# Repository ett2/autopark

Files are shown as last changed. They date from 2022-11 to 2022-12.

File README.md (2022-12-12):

# AutoPark
Repo for the embedded portion of AutoPark senior design project

Includes: 
- Lots of testing modules as keepsakes
- Fob
- Sensors
- State Driver
- Screen testing

Part of this project was developed for a course called ENGI 301. All relevant files to that class are in the ENGI 301 folder.
For further information about that portion of the project, go to:
https://www.hackster.io/eunice-tan/remote-controlled-lighting-system-b601c9

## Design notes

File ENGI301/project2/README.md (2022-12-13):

# ENGI 301 Project 2 Documentation

I developed a PCB design for the fob portion of the AutoPark project, which is designed to be a first-iteration test of the components in a PCB.
This was also designed as a part of the ENGI 301 Project 2.

Included in this directory:
- Schematic file
- Board file
- Parts library
- Bill of Materials
- Gerber files
- Pictures of the PCB design

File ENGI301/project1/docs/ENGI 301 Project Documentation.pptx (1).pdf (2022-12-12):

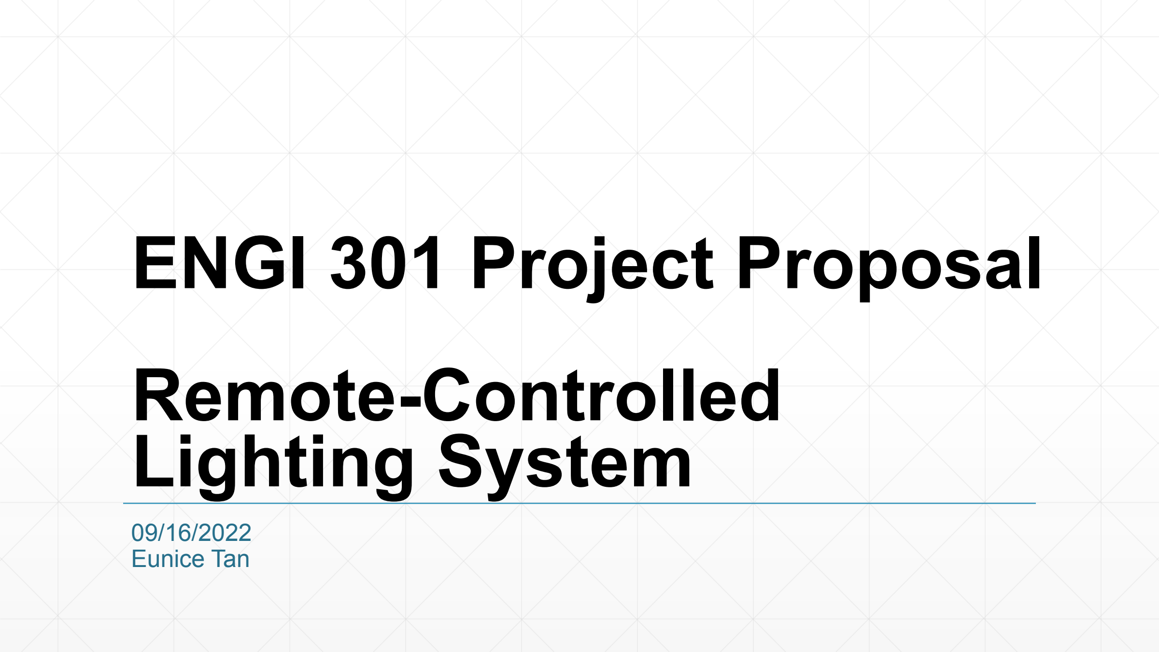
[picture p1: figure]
ENGI 301 Project Proposal; Remote-Controlled Lighting System; 09/16/2022 Eunice Tan

# Background Information

- Senior Design Project: to design a self-parking vehicle
- Need a way to communicate between the user and the golf cart used in the project
- Idea: a fob that communicates with the central processing unit of the motor control to determine state control for the vehicle
- MVP:
- Must communicate states between Arduino and BeagleBone Black with RF
- Must show state on LCD screen
- Ultrasonic sensor induces emergency stop state
- Four modes: Curbside Parking, Normal Parking, Idle, and Emergency Stop

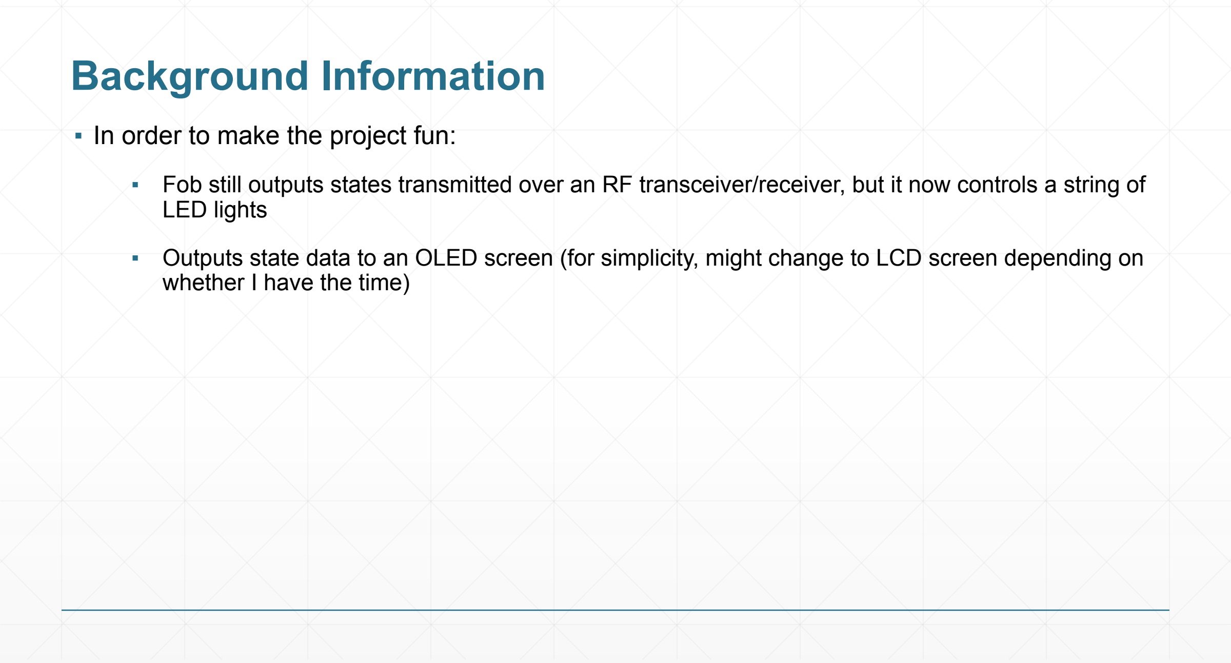
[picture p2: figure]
Background Information; ▪ In order to make the project fun:; LED lights; whether I have the time)

- Fob still outputs states transmitted over an RF transceiver/receiver, but it now controls a string of
- Outputs state data to an OLED screen (for simplicity, might change to LCD screen depending on

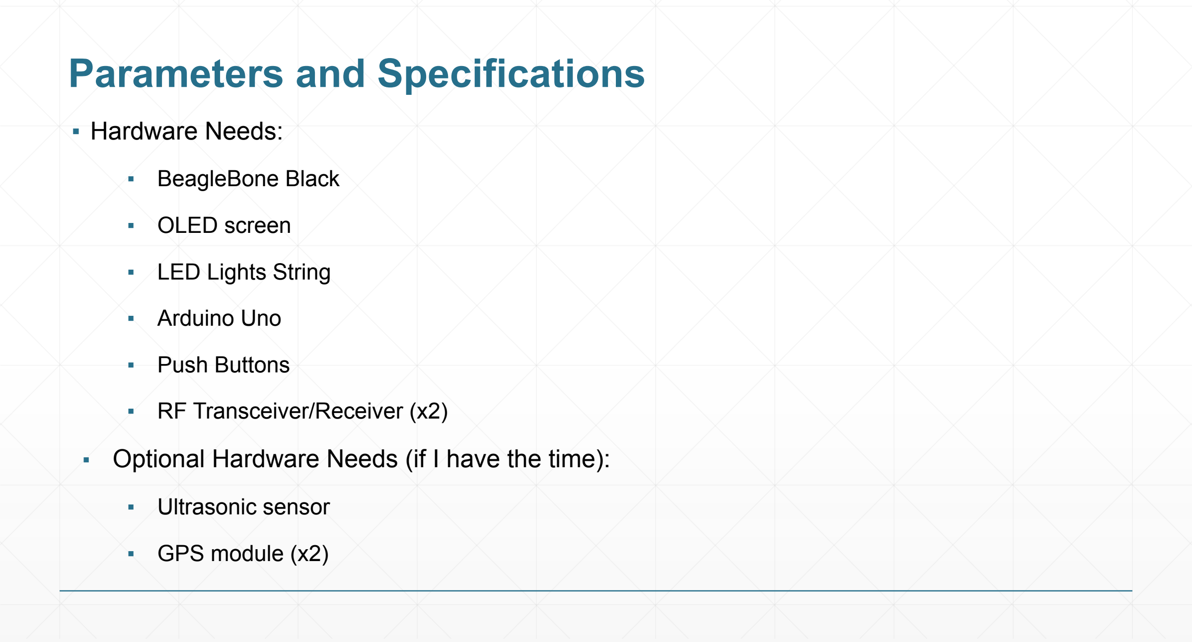
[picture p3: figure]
Parameters and Specifications; ▪ Hardware Needs:; ▪ BeagleBone Black; ▪ OLED screen; ▪ LED Lights String; ▪ Arduino Uno; ▪ Push Buttons; ▪ RF Transceiver/Receiver (x2); ▪ Ultrasonic sensor; ▪ GPS module (x2)

- Optional Hardware Needs (if I have the time):

# Parameters and Specifications

- Software Needs:
- BeagleBone Black displays state and controls the LEDs
- OLED screen displays current state
- LEDs light up differently depending on the current state
- Arduino Uno decides state transitions and communicates them to the BeagleBone
- Push buttons decide state transitions
- RF Transceiver/Receiver communicates between BeagleBone and Arduino
- Optional Software Needs:
- Ultrasonic sensor contributes to state change; BeagleBone then decides final states
- GPS modules send location information between Arduino and BeagleBone

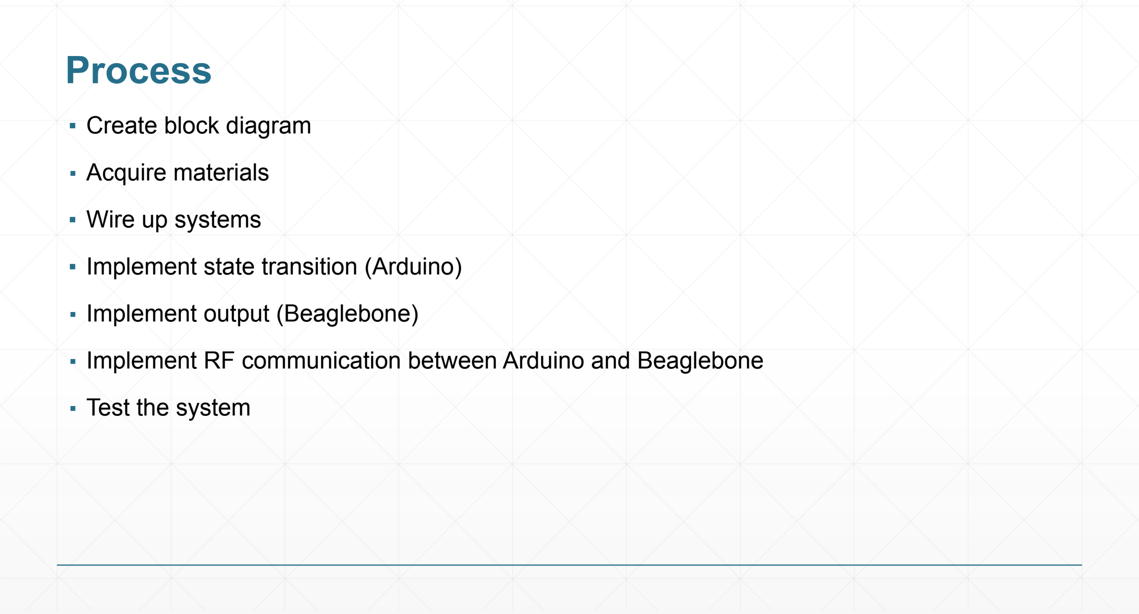
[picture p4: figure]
Process; ▪ Create block diagram; ▪ Acquire materials; ▪ Wire up systems; ▪ Implement state transition (Arduino); ▪ Implement output (Beaglebone); ▪ Test the system

- Implement RF communication between Arduino and Beaglebone

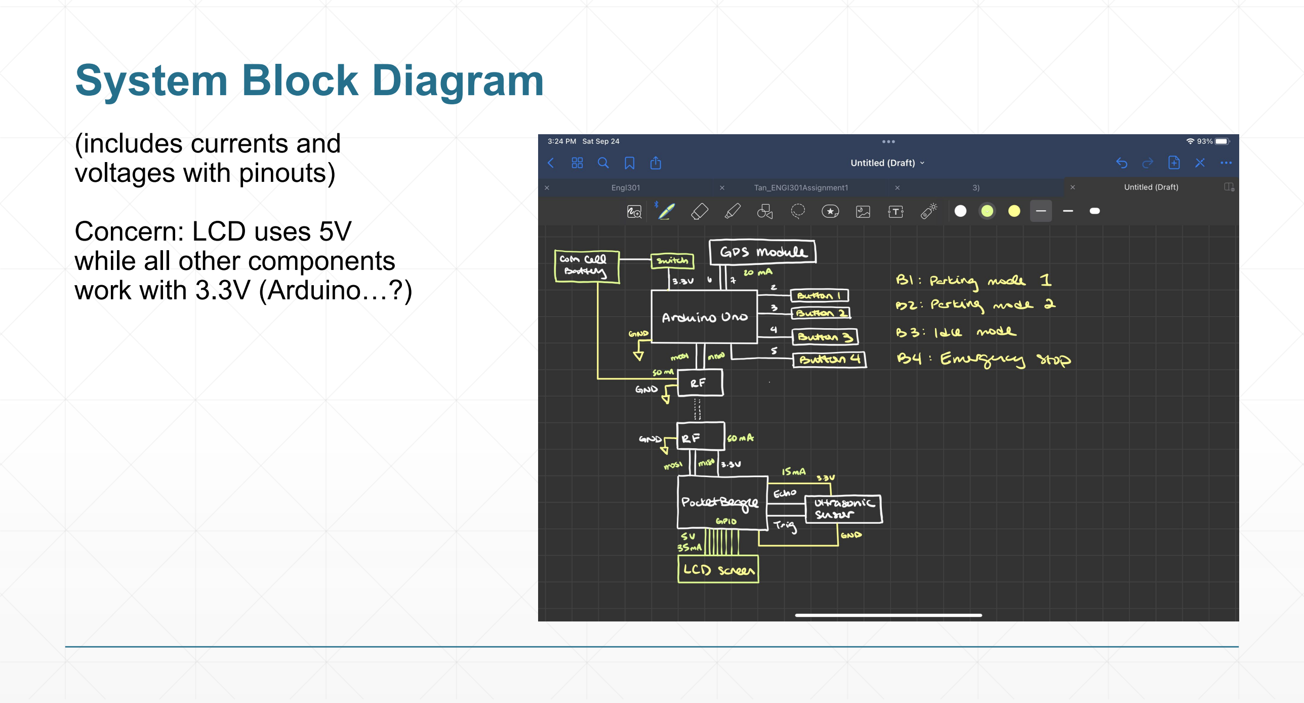
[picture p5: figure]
System Block Diagram; (includes currents and voltages with pinouts); Concern: LCD uses 5V while all other components work with 3.3V (Arduino…?)

# Components

Component | Link to Component
BeagleBone Black | N/A
Arduino Uno | https://www.amazon.com/Arduino-A000066-ARDUINO-UNO-R3/dp/B008GRTS V6
RF Module (x2) | https://www.adafruit.com/product/3071
GPS Module (x1) | https://www.adafruit.com/product/746
OLED Screen | https://www.adafruit.com/product/2719
Ultrasonic Sensor | https://www.adafruit.com/product/3942
LED Lights String | https://www.adafruit.com/product/1138?length=1
Push Buttons | N/A
Colored LEDs | N/A

Need all components to be purchased by instructor listed; additional components may be purchased by student

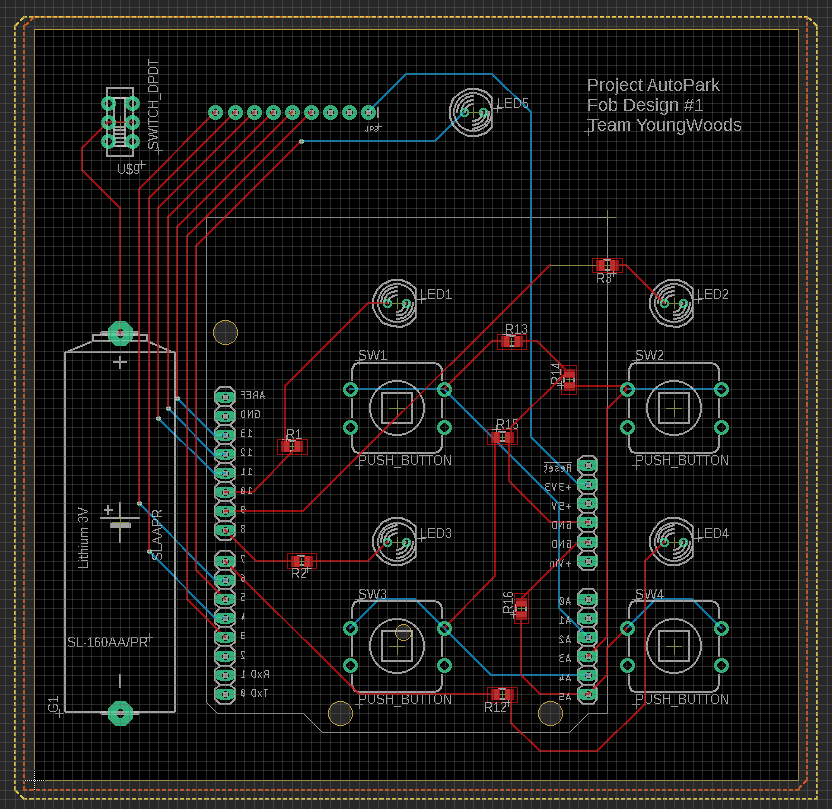
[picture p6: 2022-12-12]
ENGI301/project2/docs/fob_brd.png

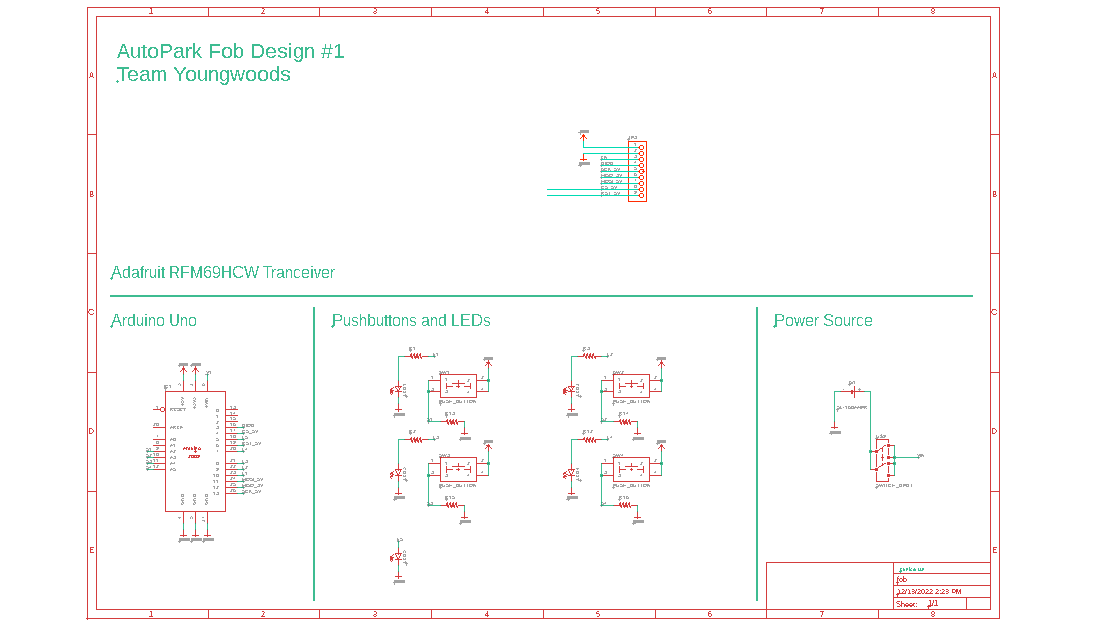
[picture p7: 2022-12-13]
ENGI301/project2/docs/fob_sch.png

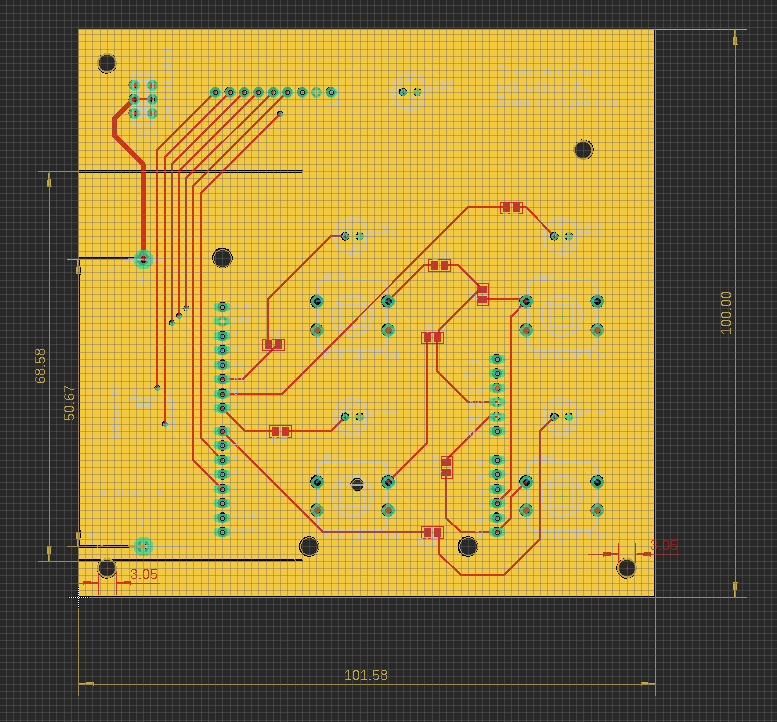
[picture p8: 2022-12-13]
ENGI301/project2/docs/fob_brd_final.png

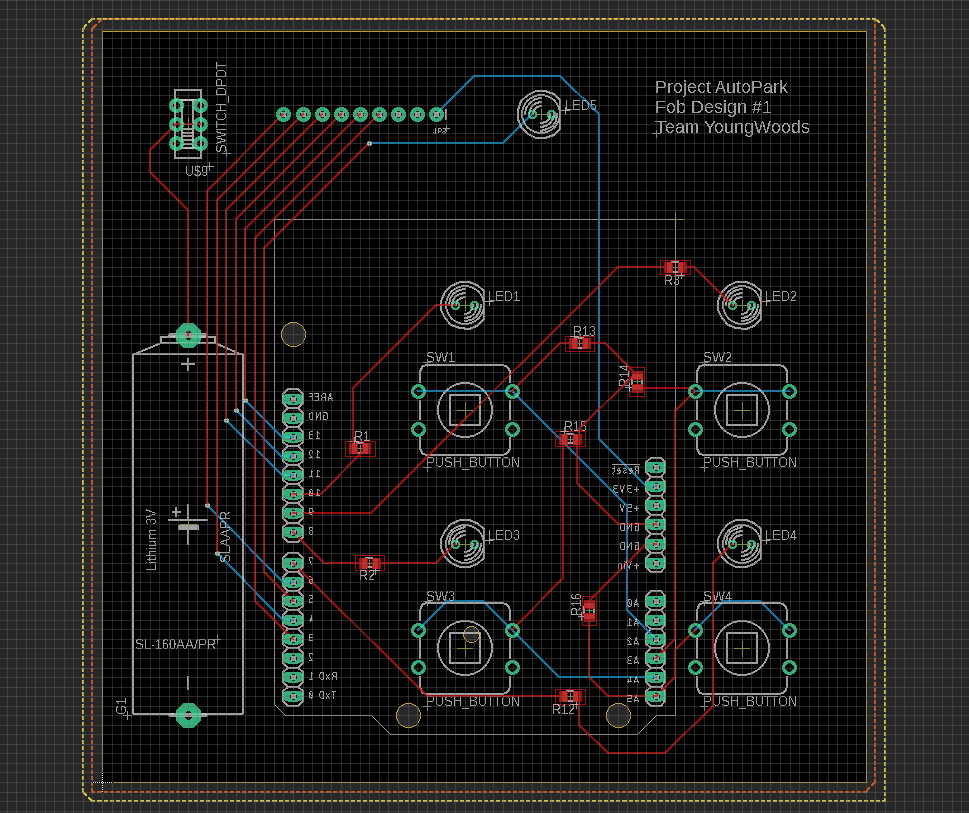
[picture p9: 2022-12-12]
ENGI301/project2/docs/fob_brd3.png

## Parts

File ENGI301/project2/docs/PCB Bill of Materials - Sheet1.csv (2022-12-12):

Part Name | Designator | Manufacturer/MPN | Quanitity | Description
Arduino Uno | Arduino 2009 | Arduino | 1 | Microcontroller board
6-pin Switch | SWITCH_DPDT | Various manufacturers | 1 | Found in FEP: no need to order
5mm LED | LED1, LED2, LED3, LED4, LED5 | Various manufacturers | 5 | Found in OEDK and FEP: no need to order
RFM69HCW Radio Module | JP3 | Adafruit | 1 | Radio transceiver/receiver module
Tactile Push Buttons | SW1, SW2, SW3, SW4 | Various manufacturers | 4 | Found in OEDK: no need to order
100-ohm resistor | R1, R2, R3, R12, R13, R14, R15, R16 | Various manufacturers | 8 | Found in FEP: no need to order
Through-hole power source connector | G1 | N/A | 1 | Can connect to various power sources depending on need

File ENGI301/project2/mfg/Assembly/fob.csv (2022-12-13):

Qty | Value | Device | Package | Parts | Description | POPULARITY
1 |  | ARDUINO2009_10 | ARDUINO2009 | IC1 | The Arduino Duemilanove (2009") is a microcontroller board based on the ATmega168 or ATmega328."
1 |  | HEADER-1X970MIL | 1X09_ROUND_70 | JP3 | PIN HEADER
5 |  | LED5MM | LED5MM | LED1, LED2, LED3, LED4, LED5 | LED | 93
8 |  | R_R0805 | R0805 | R1, R2, R3, R12, R13, R14, R15, R16 | RESISTOR, American symbol
4 | PUSH_BUTTON | PUSH_BUTTON | BUTTON_12.5MM | SW1, SW2, SW3, SW4
1 | SL-160AA/PR | SL-160AA/PR | SL-160AA/PR | G1 | LI BATTERY Sonnenschein | 1
1 | SWITCH_DPDT | SWITCH_DPDT | JS_DPDT_TH | U$9

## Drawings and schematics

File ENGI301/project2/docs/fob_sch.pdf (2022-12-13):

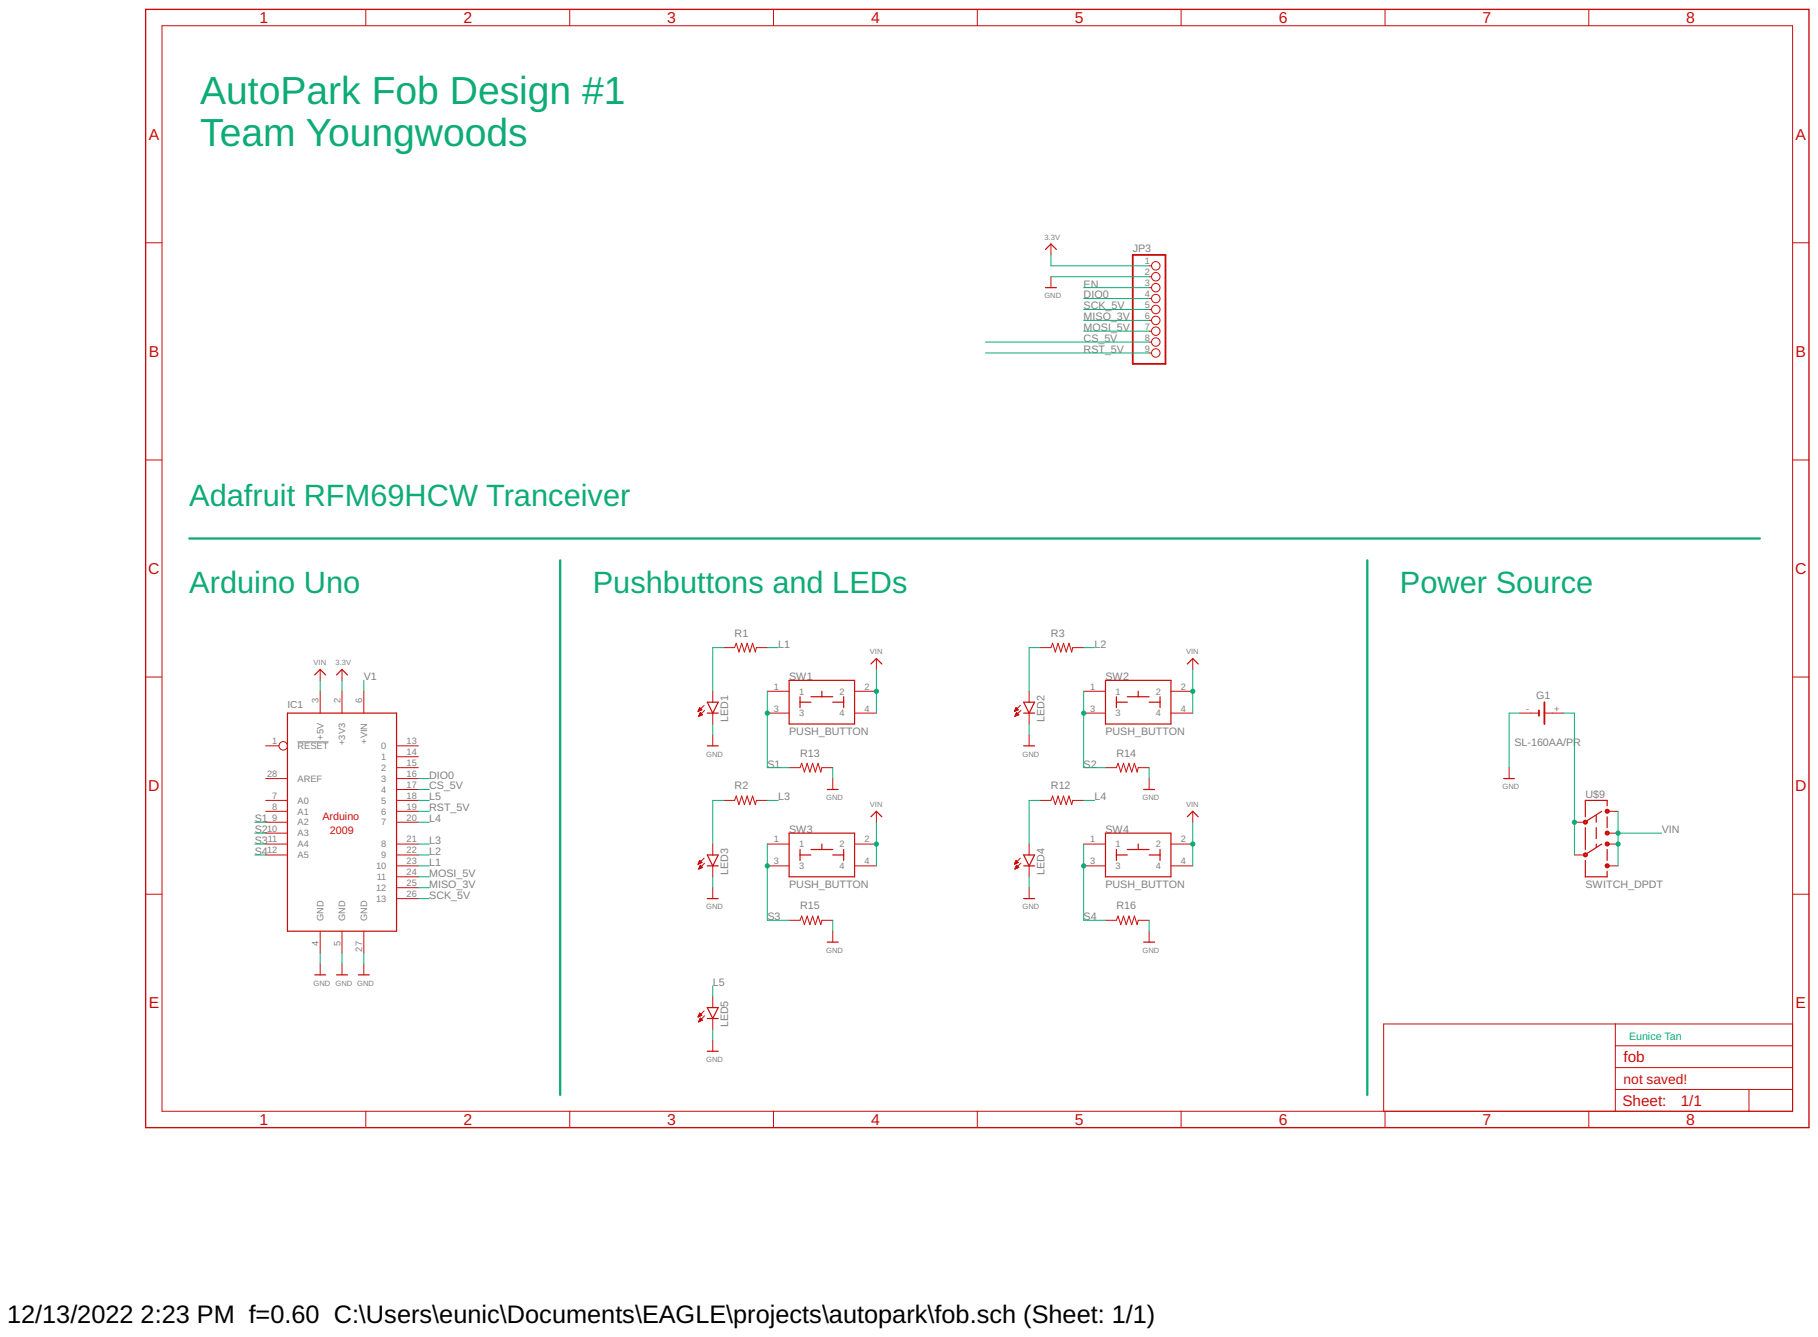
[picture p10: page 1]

12/13/2022 2:23 PM f=0.60 C:\Users\eunic\Documents\EAGLE\projects\autopark\fob.sch (Sheet: 1/1)

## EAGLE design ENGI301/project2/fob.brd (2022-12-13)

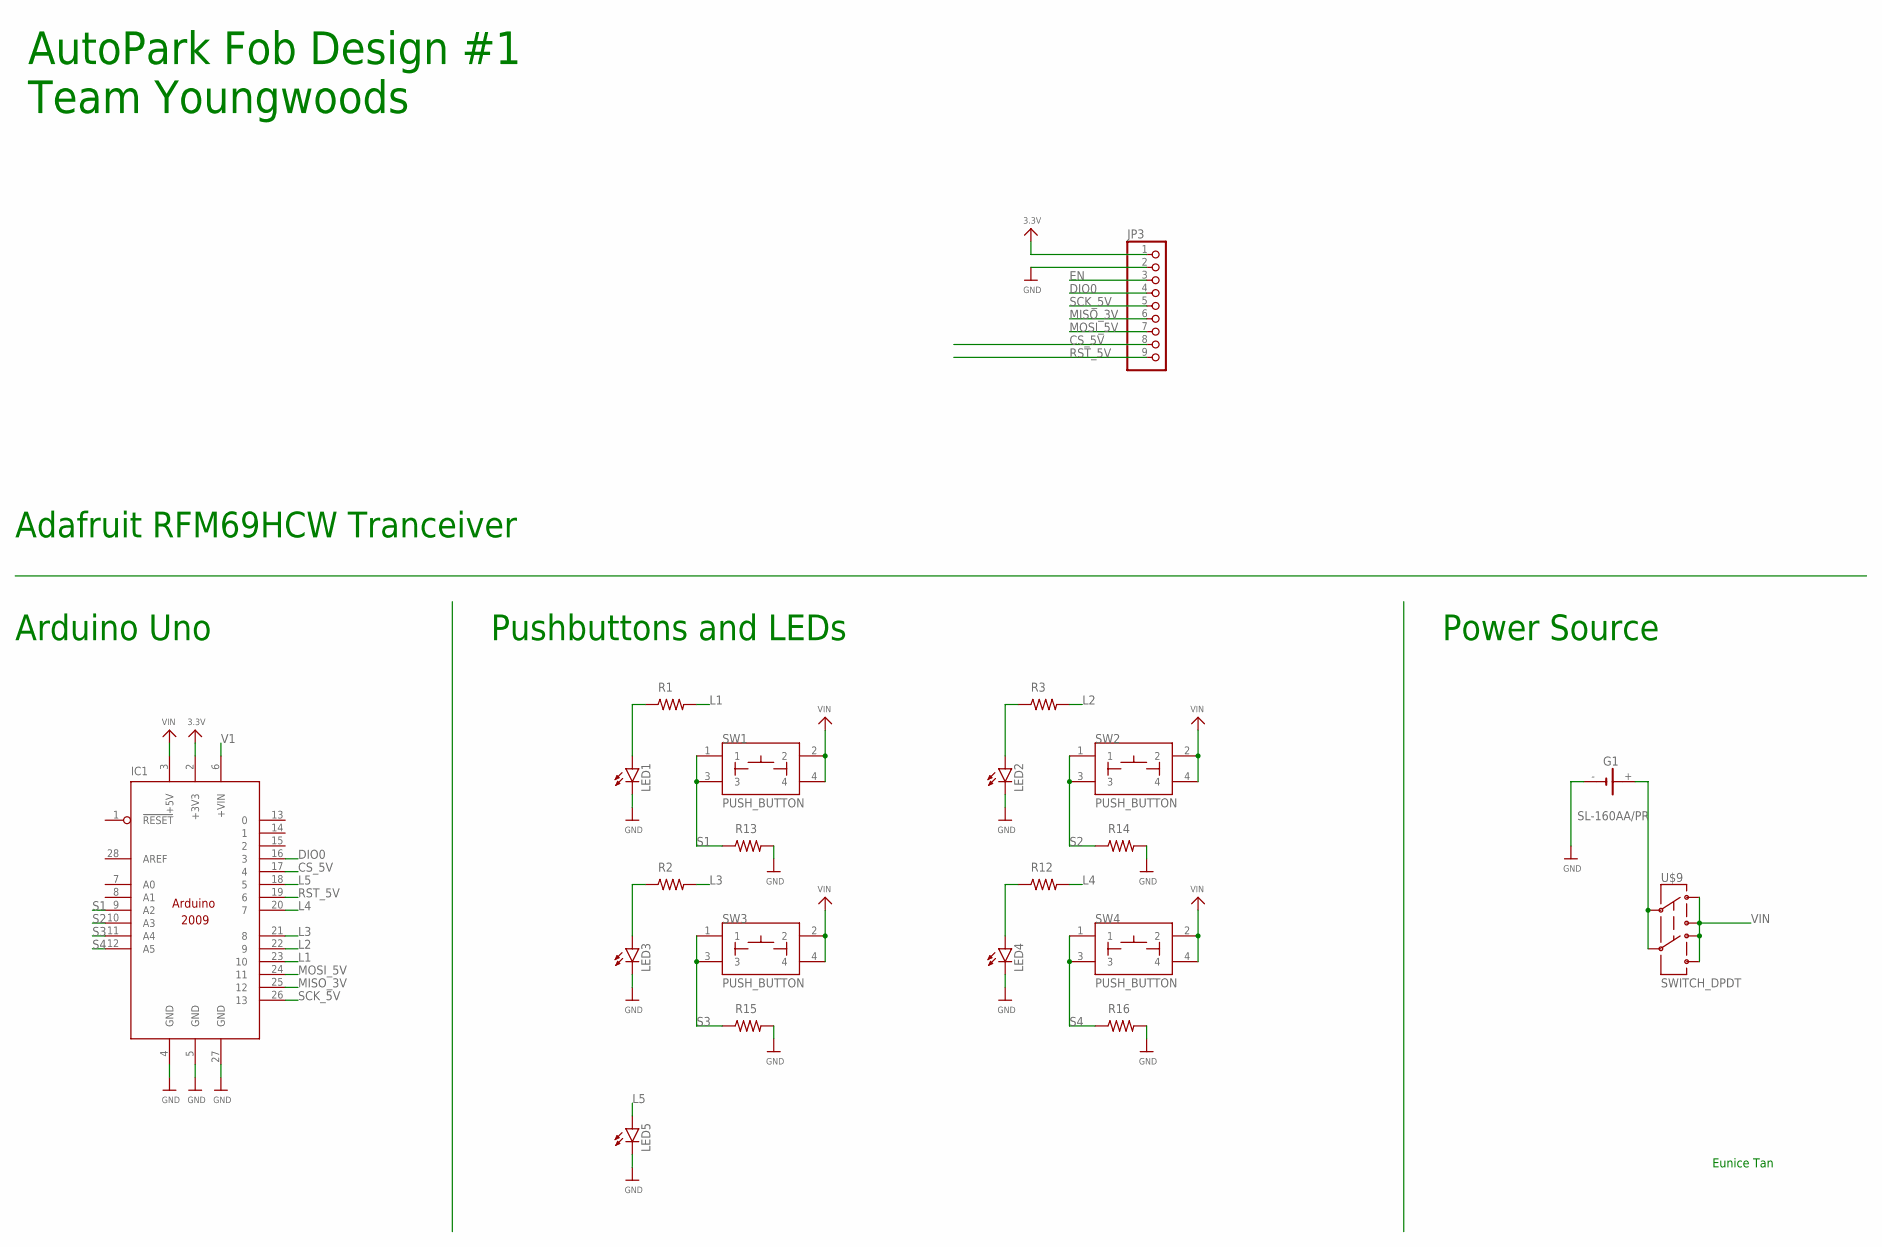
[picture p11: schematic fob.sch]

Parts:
G1: SL-160AA/PR
IC1: ARDUINO2009_10; ARDUINO2009
JP3: HEADER-1X970MIL; 1X09_ROUND_70
LED1, LED2, LED3, LED4, LED5: LED5MM
R1, R2, R3, R12, R13, R14, R15, R16: R_R0805; R0805
SW1, SW2, SW3, SW4: PUSH_BUTTON; BUTTON_12.5MM
U$9: SWITCH_DPDT; JS_DPDT_TH

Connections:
3.3V: IC1.2 (+3V3), JP3.1
CS_5V: IC1.17 (4), JP3.8
DIO0: IC1.16 (3), JP3.4
EN: JP3.3
GND: G1.-, IC1.4 (GND), IC1.5 (GND), IC1.27 (GND), JP3.2, LED1.K (C), LED2.K (C), LED3.K (C), LED4.K (C), LED5.K (C), R13.2, R14.2, R15.2, R16.2
L1: IC1.23 (10), R1.2
L2: IC1.22 (9), R3.2
L3: IC1.21 (8), R2.2
L4: IC1.20 (7), R12.2
L5: IC1.18 (5), LED5.A
MISO_3V: IC1.25 (12), JP3.6
MOSI_5V: IC1.24 (11), JP3.7
unnamed: G1.+, U$9.2, U$9.5
unnamed: LED1.A, R1.1
unnamed: LED3.A, R2.1
unnamed: LED2.A, R3.1
unnamed: LED4.A, R12.1
RST_5V: IC1.19 (6), JP3.9
S1: IC1.9 (A2), R13.1, SW1.1, SW1.3
S2: IC1.10 (A3), R14.1, SW2.1, SW2.3
S3: IC1.11 (A4), R15.1, SW3.1, SW3.3
S4: IC1.12 (A5), R16.1, SW4.1, SW4.3
SCK_5V: IC1.26 (13), JP3.5
V1: IC1.6 (+VIN)
VIN: IC1.3 (+5V), SW1.2, SW1.4, SW2.2, SW2.4, SW3.2, SW3.4, SW4.2, SW4.4, U$9.1, U$9.3, U$9.4, U$9.6

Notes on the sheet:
Adafruit RFM69HCW Tranceiver
Arduino Uno
Pushbuttons and LEDs
Power Source
Eunice Tan
AutoPark Fob Design #1 Team Youngwoods

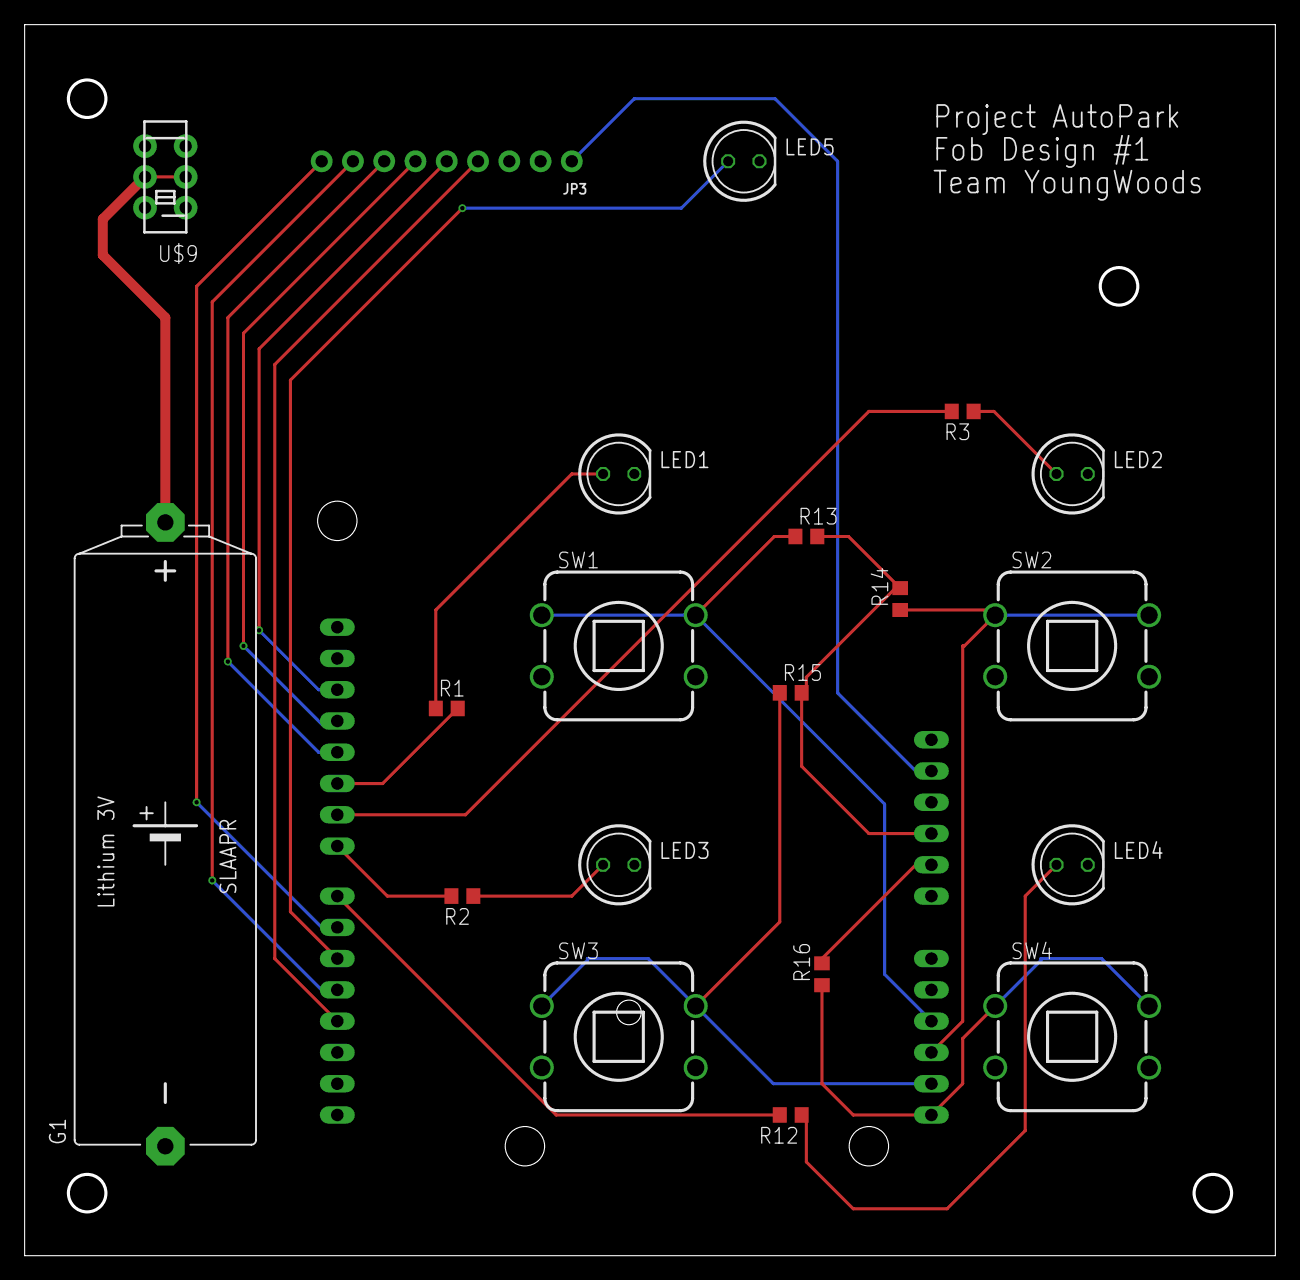
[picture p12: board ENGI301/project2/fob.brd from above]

Board: 4 copper layers, 101.6 x 100.0 mm, 21 parts (1 on the bottom side), 23 nets.

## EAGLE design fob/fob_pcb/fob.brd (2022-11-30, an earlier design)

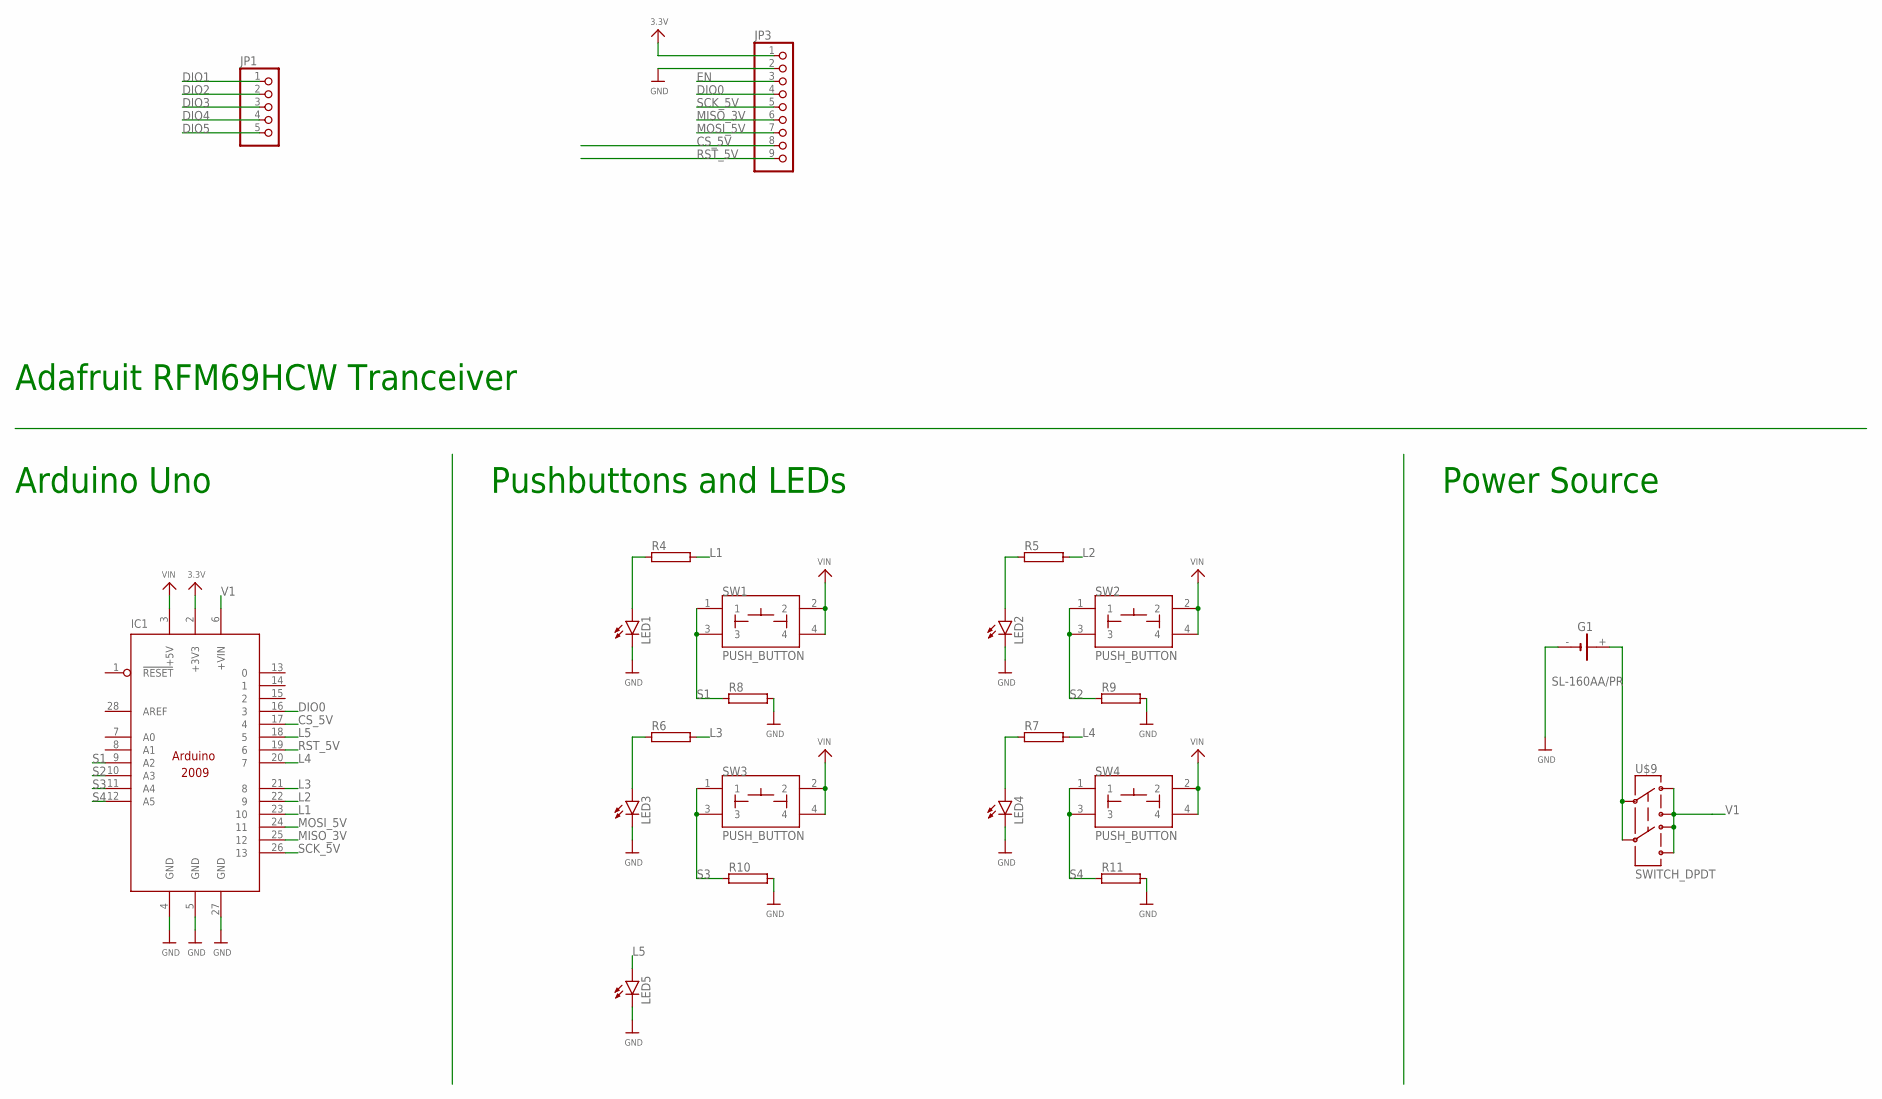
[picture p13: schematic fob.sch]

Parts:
G1: SL-160AA/PR
IC1: ARDUINO2009_10; ARDUINO2009
JP1: HEADER-1X570MIL; 1X05_ROUND_70
JP3: HEADER-1X970MIL; 1X09_ROUND_70
LED1, LED2, LED3, LED4, LED5: LED5MM
R4, R5, R6, R7, R8, R9, R10, R11: RAC01; AC01
SW1, SW2, SW3, SW4: PUSH_BUTTON; BUTTON_12.5MM
U$9: SWITCH_DPDT; JS_DPDT_TH

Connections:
3.3V: IC1.2 (+3V3), JP3.1
CS_5V: IC1.17 (4), JP3.8
DIO0: IC1.16 (3), JP3.4
DIO1: JP1.1
DIO2: JP1.2
DIO3: JP1.3
DIO4: JP1.4
DIO5: JP1.5
EN: JP3.3
GND: G1.-, IC1.4 (GND), IC1.5 (GND), IC1.27 (GND), JP3.2, LED1.K (C), LED2.K (C), LED3.K (C), LED4.K (C), LED5.K (C), R8.2, R9.2, R10.2, R11.2
L1: IC1.23 (10), R4.2
L2: IC1.22 (9), R5.2
L3: IC1.21 (8), R6.2
L4: IC1.20 (7), R7.2
L5: IC1.18 (5), LED5.A
MISO_3V: IC1.25 (12), JP3.6
MOSI_5V: IC1.24 (11), JP3.7
unnamed: G1.+, U$9.2, U$9.5
unnamed: LED1.A, R4.1
unnamed: LED3.A, R6.1
unnamed: LED2.A, R5.1
unnamed: LED4.A, R7.1
RST_5V: IC1.19 (6), JP3.9
S1: IC1.9 (A2), R8.1, SW1.1, SW1.3
S2: IC1.10 (A3), R9.1, SW2.1, SW2.3
S3: IC1.11 (A4), R10.1, SW3.1, SW3.3
S4: IC1.12 (A5), R11.1, SW4.1, SW4.3
SCK_5V: IC1.26 (13), JP3.5
V1: IC1.6 (+VIN), U$9.1, U$9.3, U$9.4, U$9.6
VIN: IC1.3 (+5V), SW1.2, SW1.4, SW2.2, SW2.4, SW3.2, SW3.4, SW4.2, SW4.4

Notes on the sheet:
Adafruit RFM69HCW Tranceiver
Arduino Uno
Pushbuttons and LEDs
Power Source

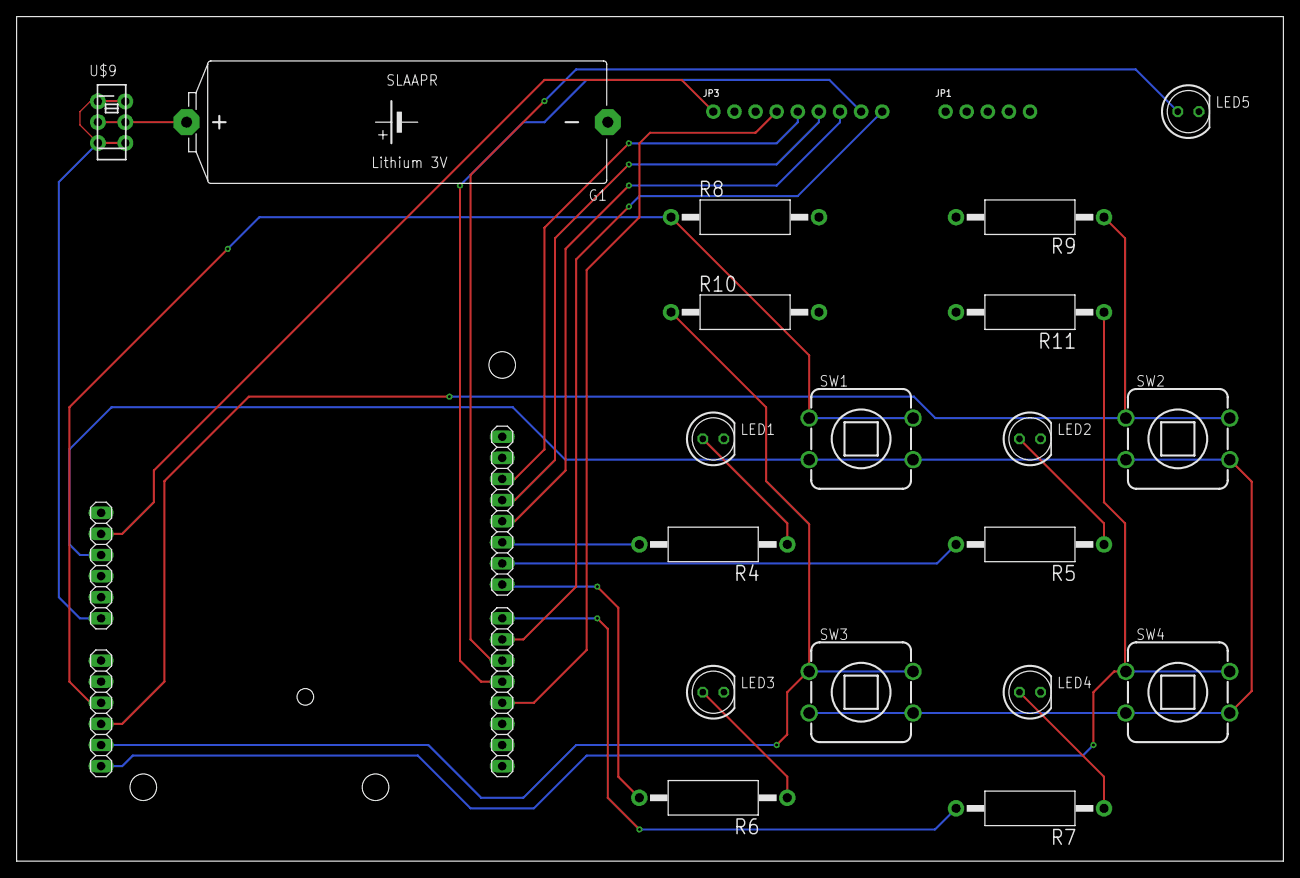
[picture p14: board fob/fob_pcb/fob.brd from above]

Board: 2 copper layers, 152.4 x 101.6 mm, 22 parts (0 on the bottom side), 24 nets.

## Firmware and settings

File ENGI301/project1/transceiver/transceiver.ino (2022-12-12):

/*
--------------------------------------------------------------------------
RF Transceiver (0)
--------------------------------------------------------------------------
License:   
Copyright 2022 Eunice Tan
Redistribution and use in source and binary forms, with or without 
modification, are permitted provided that the following conditions are met:
1. Redistributions of source code must retain the above copyright notice, this 
list of conditions and the following disclaimer.
2. Redistributions in binary form must reproduce the above copyright notice, 
this list of conditions and the following disclaimer in the documentation 
and/or other materials provided with the distribution.
3. Neither the name of the copyright holder nor the names of its contributors 
may be used to endorse or promote products derived from this software without 
specific prior written permission.
THIS SOFTWARE IS PROVIDED BY THE COPYRIGHT HOLDERS AND CONTRIBUTORS "AS IS" 
AND ANY EXPRESS OR IMPLIED WARRANTIES, INCLUDING, BUT NOT LIMITED TO, THE 
IMPLIED WARRANTIES OF MERCHANTABILITY AND FITNESS FOR A PARTICULAR PURPOSE ARE 
DISCLAIMED. IN NO EVENT SHALL THE COPYRIGHT HOLDER OR CONTRIBUTORS BE LIABLE 
FOR ANY DIRECT, INDIRECT, INCIDENTAL, SPECIAL, EXEMPLARY, OR CONSEQUENTIAL 
DAMAGES (INCLUDING, BUT NOT LIMITED TO, PROCUREMENT OF SUBSTITUTE GOODS OR 
SERVICES; LOSS OF USE, DATA, OR PROFITS; OR BUSINESS INTERRUPTION) HOWEVER 
CAUSED AND ON ANY THEORY OF LIABILITY, WHETHER IN CONTRACT, STRICT LIABILITY, 
OR TORT (INCLUDING NEGLIGENCE OR OTHERWISE) ARISING IN ANY WAY OUT OF THE USE 
OF THIS SOFTWARE, EVEN IF ADVISED OF THE POSSIBILITY OF SUCH DAMAGE.
--------------------------------------------------------------------------
This does a few things:
- Gets state information from transceiver
- Outputs this information as an encoder
--------------------------------------------------------------------------
Adapted from:
https://learn.adafruit.com/adafruit-feather-32u4-radio-with-rfm69hcw-module/using-the-rfm69-radio
https://github.com/sparkfun/SparkFun_RadioHead_Arduino_Library
*/


#include <SPI.h>
#include <RH_RF69.h>

// ------------------------------------------------------------------------
// Global Variables
// ------------------------------------------------------------------------

/************ Radio Setup ***************/

#define RF69_FREQ 433.0

#define RFM69_CS      4
#define RFM69_INT     3
#define RFM69_RST     6
#define LED           5  

// Singleton instance of the radio driver
RH_RF69 rf69(RFM69_CS, RFM69_INT);

int16_t packetnum = 0;  // packet counter, we increment per xmission

/************ Button Setup **************/
const int b1 = A5;  // mode 1
const int b2 = A4;  // mode 2
const int b3 = A3;  // mode idle
const int b4 = A2;  // mode stop
const int buttonpress = 2; // /button interrupt 

/************ LED Setup *****************/

const int LED1 = 7;
const int LED2 = 8;
const int LED3 = 9;
const int LED4 = 10;

/************ State Setup ***************/

volatile int b1state = LOW;
volatile int b2state = LOW;
volatile int b3state = LOW;
volatile int b4state = LOW;

volatile byte state = 0;

volatile char message = '0';

// ------------------------------------------------------------------------
// Setup
// ------------------------------------------------------------------------

void setup() {
  Serial.begin(9600);

  // Radio setup
  pinMode(LED, OUTPUT);     
  pinMode(RFM69_RST, OUTPUT);
  digitalWrite(RFM69_RST, LOW);

  // manual reset
  radio_reset();
  
  
  // Defaults after init are 434.0MHz, modulation GFSK_Rb250Fd250, +13dbM (for low power module)
  // No encryption
  if (!rf69.setFrequency(RF69_FREQ)) {
    Serial.println("setFrequency failed");
  }

  // If you are using a high power RF69 eg RFM69HW, you *must* set a Tx power with the
  // ishighpowermodule flag set like this:
  rf69.setTxPower(20, true);  // range from 14-20 for power, 2nd arg must be true for 69HCW

  // The encryption key has to be the same as the one in the server
  uint8_t key[] = { 0x01, 0x02, 0x03, 0x04, 0x05, 0x06, 0x07, 0x08,
                    0x01, 0x02, 0x03, 0x04, 0x05, 0x06, 0x07, 0x08};
  rf69.setEncryptionKey(key);

  Serial.print("RFM69 radio @");  Serial.print((int)RF69_FREQ);  Serial.println(" MHz");

  // Fob setup
  pinMode(buttonpress, OUTPUT);
  pinMode(b1, INPUT_PULLUP);
  pinMode(b2, INPUT_PULLUP);
  pinMode(b3, INPUT_PULLUP);
  pinMode(b4, INPUT_PULLUP);
  pinMode(LED1, OUTPUT);
  pinMode(LED2, OUTPUT);

  Serial.println("Fob setup complete!");
  // initialize interrupt
  attachInterrupt(digitalPinToInterrupt(buttonpress), statechange, RISING);
}

// ------------------------------------------------------------------------
// Main Loop
// ------------------------------------------------------------------------

void loop() {
  b1state = digitalRead(b1);
  b2state = digitalRead(b2);
  b3state = digitalRead(b3);
  b4state = digitalRead(b4);
  //delay(1);

  // detects button press and sends message
  if (b1state == HIGH || b2state == HIGH || b3state == HIGH || b4state == HIGH) {
    digitalWrite(buttonpress, HIGH);
    send_message();
    Blink(LED, 40, 3);
    // receive_message();
  }
  else { 
    digitalWrite(buttonpress, LOW);
  }

  delay(1);
  //Serial.println(state);
}

// ------------------------------------------------------------------------
// State Change
// ------------------------------------------------------------------------

void statechange() {
  // calls message function
  if (b1state == HIGH) {
    state = 1;
    digitalWrite(LED1, HIGH);
    digitalWrite(LED2, LOW);
    digitalWrite(LED3, LOW);
    digitalWrite(LED4, LOW);
  } else if (b2state == HIGH) {
    state = 2;
    digitalWrite(LED1, LOW);
    digitalWrite(LED2, HIGH);
    digitalWrite(LED3, LOW);
    digitalWrite(LED4, LOW);
 } else if (b3state == HIGH) {
    state = 3;
    digitalWrite(LED1, LOW);
    digitalWrite(LED2, LOW);
    digitalWrite(LED3, HIGH);
    digitalWrite(LED4, LOW);
  } else if (b4state == HIGH) {
    state = 4;
    digitalWrite(LED1, LOW);
    digitalWrite(LED2, LOW);
    digitalWrite(LED3, LOW);
    digitalWrite(LED4, HIGH);
  } else {
    digitalWrite(LED1, LOW);
    digitalWrite(LED2, LOW);
    digitalWrite(LED3, LOW);
    digitalWrite(LED4, LOW);
    }
  digitalWrite(buttonpress, LOW);

}

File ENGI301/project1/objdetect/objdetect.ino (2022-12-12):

/*
--------------------------------------------------------------------------
Object Detection Module
--------------------------------------------------------------------------
License:   
Copyright 2022 Eunice Tan
Redistribution and use in source and binary forms, with or without 
modification, are permitted provided that the following conditions are met:
1. Redistributions of source code must retain the above copyright notice, this 
list of conditions and the following disclaimer.
2. Redistributions in binary form must reproduce the above copyright notice, 
this list of conditions and the following disclaimer in the documentation 
and/or other materials provided with the distribution.
3. Neither the name of the copyright holder nor the names of its contributors 
may be used to endorse or promote products derived from this software without 
specific prior written permission.
THIS SOFTWARE IS PROVIDED BY THE COPYRIGHT HOLDERS AND CONTRIBUTORS "AS IS" 
AND ANY EXPRESS OR IMPLIED WARRANTIES, INCLUDING, BUT NOT LIMITED TO, THE 
IMPLIED WARRANTIES OF MERCHANTABILITY AND FITNESS FOR A PARTICULAR PURPOSE ARE 
DISCLAIMED. IN NO EVENT SHALL THE COPYRIGHT HOLDER OR CONTRIBUTORS BE LIABLE 
FOR ANY DIRECT, INDIRECT, INCIDENTAL, SPECIAL, EXEMPLARY, OR CONSEQUENTIAL 
DAMAGES (INCLUDING, BUT NOT LIMITED TO, PROCUREMENT OF SUBSTITUTE GOODS OR 
SERVICES; LOSS OF USE, DATA, OR PROFITS; OR BUSINESS INTERRUPTION) HOWEVER 
CAUSED AND ON ANY THEORY OF LIABILITY, WHETHER IN CONTRACT, STRICT LIABILITY, 
OR TORT (INCLUDING NEGLIGENCE OR OTHERWISE) ARISING IN ANY WAY OUT OF THE USE 
OF THIS SOFTWARE, EVEN IF ADVISED OF THE POSSIBILITY OF SUCH DAMAGE.
--------------------------------------------------------------------------
This does a few things:
- Checks Distance from multiple HCSR04 sensors
- If an object is detected under a certain threshold, pulls up a pin and lights up an LED
--------------------------------------------------------------------------
Adapted from:
https://create.arduino.cc/projecthub/abdularbi17/ultrasonic-sensor-hc-sr04-with-arduino-tutorial-327ff6

*/


// ------------------------------------------------------------------------
// Global Variables
// ------------------------------------------------------------------------

// Pin setup
#define trig0 5
#define echo0 6 
#define trig1 7
#define echo1 8
#define trig2 9
#define echo2 10
#define flag  4
#define state1 A5
#define state0 A4

// Variables
long duration; // duration of sound wave travel
int distance; // distance measurement
int flagstate; // emergency brake flag
int s1;
int s0;

// ------------------------------------------------------------------------
// Setup
// ------------------------------------------------------------------------
void setup() {
  pinMode(trig0, OUTPUT); // Sets the trigPin as an OUTPUT
  pinMode(echo0, INPUT); // Sets the echoPin as an INPUT
  pinMode(trig1, OUTPUT); 
  pinMode(echo1, INPUT); 
  pinMode(trig2, OUTPUT);
  pinMode(echo2, INPUT); 
  pinMode(flag, OUTPUT);
  pinMode(state1, INPUT); 
  pinMode(state0, INPUT);

  Serial.begin(9600); 
  Serial.println("Ultrasonic Sensor Emergency Braking State System"); 
  Serial.println("Setup complete :)");
}

// ------------------------------------------------------------------------
// Main Loop
// ------------------------------------------------------------------------
void loop() {
s1 = digitalRead(state1); 
s0 = digitalRead(state0);
//Serial.print("s1: ");
//Serial.println(s1);
//Serial.print("s0: ");
//Serial.println(s0);

// only detects objects in a certain state
if (s1 == 1 && s0 == 0) {
  ultrasonic(trig0, echo0);
  delay(500);
  distancecheck(distance);
  delay(500);
  ultrasonic(trig1, echo1);
  delay(500);
  distancecheck(distance);
  delay(500);
  //ultrasonic(trig2, echo2);
  //delay(1000);
  //distancecheck(distance);
  //delay(1000);
} else {
  digitalWrite(flag, LOW);
  delay(500);
}
}

// ------------------------------------------------------------------------
// Ultrasonic Sensor Distance Measurement
// ------------------------------------------------------------------------

void ultrasonic(int trig, int echo) {
  // Clears the trigPin condition
  digitalWrite(trig, LOW);
  delayMicroseconds(2);
  // Sets the trigPin HIGH (ACTIVE) for 10 microseconds
  digitalWrite(trig, HIGH);
  delayMicroseconds(10);
  digitalWrite(trig, LOW);
  // Reads the echoPin, returns the sound wave travel time in microseconds
  duration = pulseIn(echo, HIGH);
  // Calculating the distance
  distance = duration * 0.034 / 2; // Speed of sound wave divided by 2 (go and back)
  // Displays the distance on the Serial Monitor
  Serial.print("Distance: ");
  Serial.print(distance);
  Serial.println(" cm");
}

// ------------------------------------------------------------------------
// Output driver
// ------------------------------------------------------------------------
void distancecheck(int distance) {
  if (distance < 30) { // change this value to make the braking more sensitive
    digitalWrite(flag, HIGH);
    Serial.println("Emergency Brake!");
    delay(10000); // gives time for obstacle to get out of the way
  }
  else {
    digitalWrite(flag, LOW);
  }
}

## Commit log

2022-11-30 added pcb design 1 for fob
    includes brd and sch files
    [fob.brd, fob.sch]
2022-11-30 Update fob.brd
    yep
    [fob.brd]
2022-12-04 added gerber files for iteration 1
    [bottom_copper_layer.GBL, top_copper_layer.GTL]
2022-12-12 project 2 stuff
    asdlkjdaskljkljasd
    [fob.brd, fob.sch]
2022-12-12 added pcb documentation
    [PCB Bill of Materials - Sheet1.csv]
2022-12-13 added to PCB design
    - mounting holes
    - documentation
    - titles and stuff
    [fob.brd, fob.sch]
2022-12-13 Added gbr files
    [fob.brd, fob.csv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]

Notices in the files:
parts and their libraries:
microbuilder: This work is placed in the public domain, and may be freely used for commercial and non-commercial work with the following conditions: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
